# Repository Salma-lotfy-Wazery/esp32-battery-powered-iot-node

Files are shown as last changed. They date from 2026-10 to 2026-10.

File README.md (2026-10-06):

# 📡 ESP32 Battery-Powered IoT Telemetry Node



[]()
[]()

A compact, reliable, and energy-efficient custom hardware platform engineered for wireless sensor monitoring and remote telemetry applications. Built around the **Espressif ESP32-WROOM-32** module, this node combines precision sensor interfaces, on-board Lithium-Polymer (LiPo) battery charge management, and a modern USB-C interface into a robust 2-layer PCB layout.

---

## 🖼️ 3D Render & Visual Inspection

<p align="center">
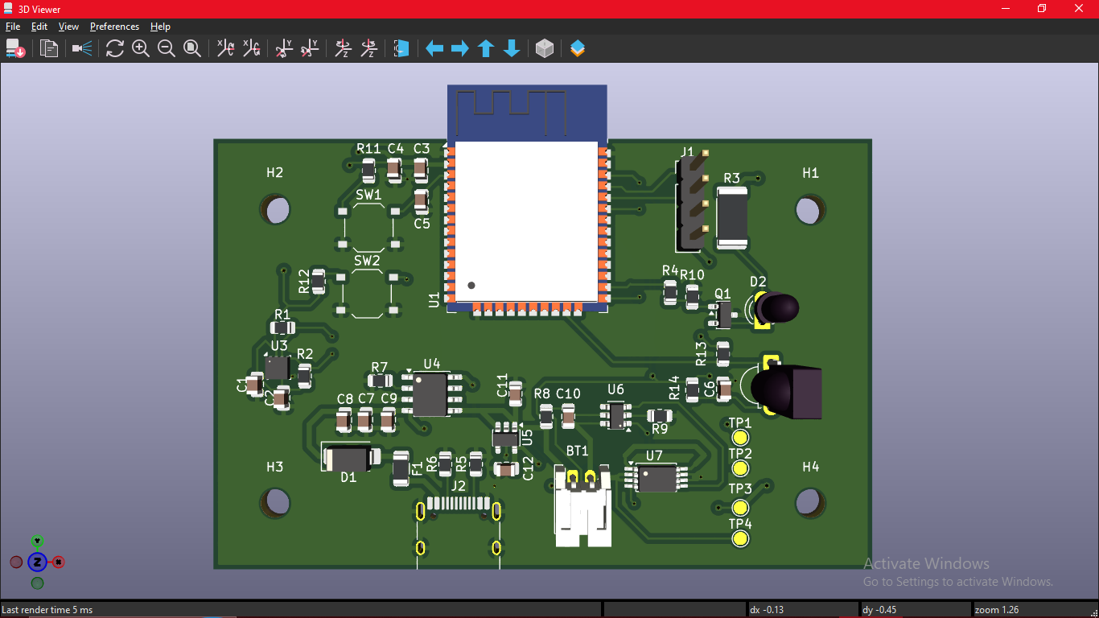
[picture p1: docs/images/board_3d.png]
ESP32 IoT Node 3D Board Perspective
  
</p>

<p align="center">
  <em>Figure 1: Full 3D assembly render of the ESP32 Battery-Powered IoT Node.</em>
</p>

---

## ⚡ Technical Architecture & Hardware Features

### 1. Power Distribution & Battery Management
- **USB Interface**: USB Type-C receptacle wired for standard 5V VBUS power negotiation and system integration.
- **Battery Charging**: Integrated Single-Cell Li-Ion/LiPo battery management circuit (Linear Constant-Current / Constant-Voltage charging) with charge-status telemetry.
- **Voltage Regulation**: Low-Dropout (LDO) regulator delivering a stable, low-noise 3.3V power rail to ensure radio stability during Wi-Fi/BLE bursts.
- **Power Path & Protection**: Reverse protection and decoupling networks mitigating voltage ripple across analog and digital loads.

### 2. Microcontroller & Sensor Interfaces
- **MCU**: ESP32-WROOM-32 high-performance dual-core 32-bit Tensilica Xtensa LX6 microprocessor operating at up to 240 MHz.
- **Wireless Connectivity**: Integrated 2.4 GHz 802.11 b/g/n Wi-Fi and Bluetooth v4.2 / BLE.
- **Telemetry Bus**: Dedicated I2C bus featuring proper pull-up resistors for multi-sensor interfacing (environmental, motion, and ambient instrumentation).
- **Control & Diagnostics**: Hardware Pushbuttons for system `EN` (Reset) and `IO0` (Bootloader Strap), plus dedicated LED indicators for power and user status.
- **Test Points**: Strategic analog and digital hardware test points for oscilloscope probing and rapid bring-up validation.

---

## 📐 PCB Layout & Documentation

| Isometric 3D Model | Top View / Layout View |
| :---: | :---: |
| 3D Angle | Top View |

### PCB Specifications
- **Board Stackup**: 2-Layer FR4 Standard
- **Finished Copper Weight**: 1 oz (35 µm)
- **Ground Strategy**: Continuous, low-impedance ground return planes on both Top and Bottom layers stitched with vias.
- **Mechanical Form Factor**: Designed with 4 corner mounting holes for standard standoffs and protective enclosure mounting.

---
## ⚖️ License

This project is licensed under the CERN Open Hardware Licence Version 2 - Weakly Reciprocal (CERN-OHL-W-2.0). See the [LICENSE](LICENSE) file for more information.

## 📂 Repository File Tree

├── project 1 pcb.kicad_pcb              # Multi-layer PCB routing and layout
├── .gitignore                           # Excludes KiCad temporary, backup & lock files
└── README.md                            # Primary project documentation

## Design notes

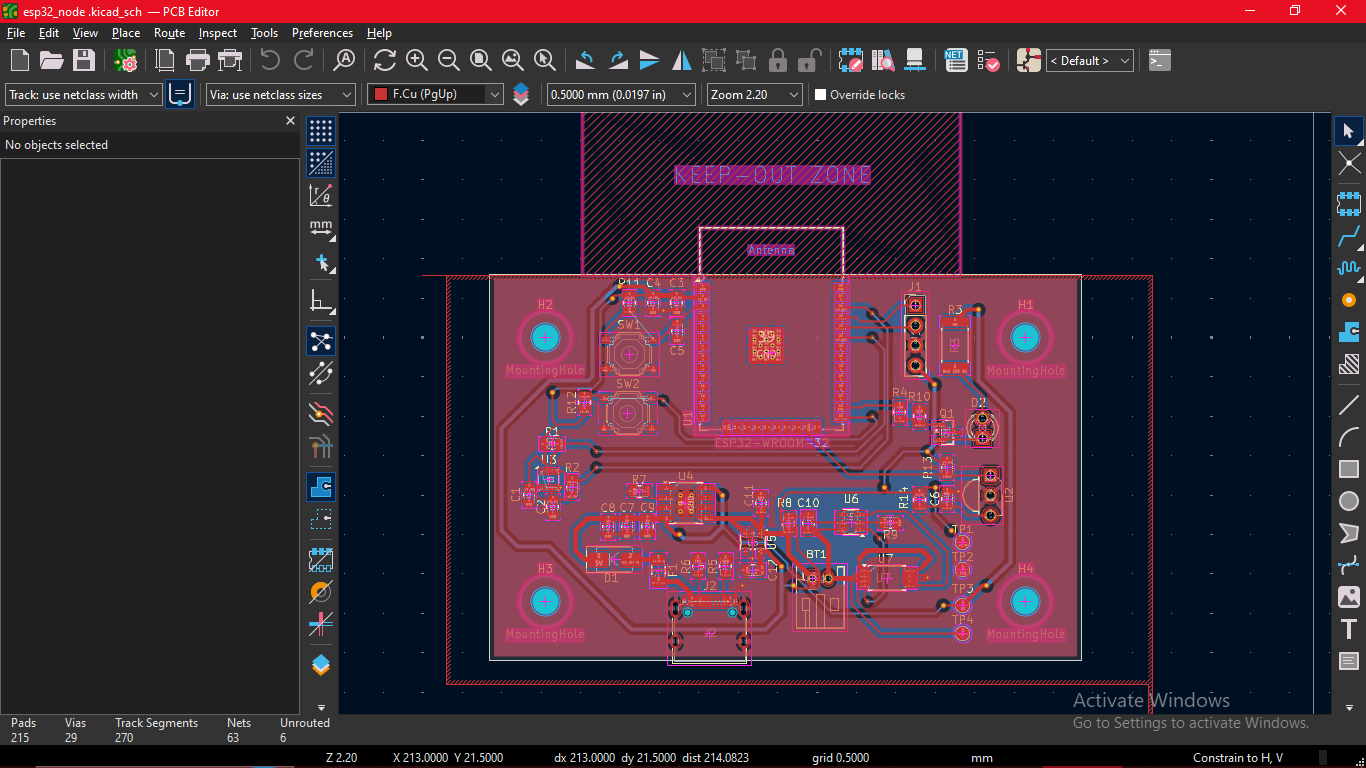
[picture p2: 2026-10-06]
docs/images/board _2d .png

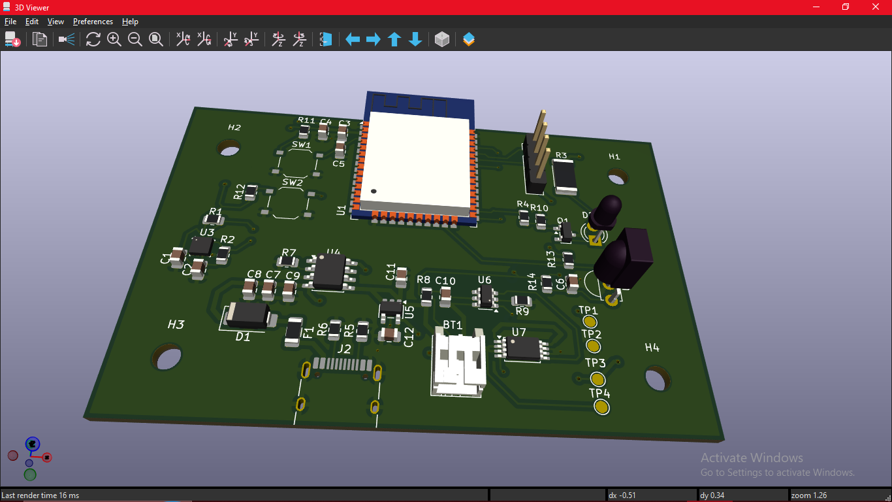
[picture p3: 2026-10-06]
docs/images/board_3d .png

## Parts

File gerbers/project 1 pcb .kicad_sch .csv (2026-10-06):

Reference | Qty | Value | DNP | Exclude from BOM | Exclude from Board | Exclude from Simulation | Exclude from Position Files | Footprint | Datasheet
BT1 | 1 | Battery_Cell |  |  |  |  | ${EXCLUDE_FROM_POS_FILES} | Connector_JST:JST_PH_S2B-PH-K_1x02_P2.00mm_Horizontal
C1,C2,C3,C5,C6,C9,C10 | 7 | 100n |  |  |  |  | ${EXCLUDE_FROM_POS_FILES} | Capacitor_SMD:C_0805_2012Metric
C4,C7,C8,C11,C12 | 5 | 10u |  |  |  |  | ${EXCLUDE_FROM_POS_FILES} | Capacitor_SMD:C_0805_2012Metric
D1 | 1 | SS14 |  |  |  |  | ${EXCLUDE_FROM_POS_FILES} | Diode_SMD:D_SMA | https://www.vishay.com/docs/88746/ss12.pdf
D2 | 1 | TSAL4400 |  |  |  |  | ${EXCLUDE_FROM_POS_FILES} | LED_THT:LED_D3.0mm_IRBlack | http://www.vishay.com/docs/81006/tsal4400.pdf
F1 | 1 | 2A |  |  |  |  | ${EXCLUDE_FROM_POS_FILES} | Fuse:Fuse_1206_3216Metric
J1 | 1 | Conn_01x04_Pin |  |  |  |  | ${EXCLUDE_FROM_POS_FILES} | Connector_PinHeader_2.54mm:PinHeader_1x04_P2.54mm_Vertical
J2 | 1 | USB_C_Receptacle_USB2.0_16P |  |  |  |  | ${EXCLUDE_FROM_POS_FILES} | Connector_USB:USB_C_Receptacle_HRO_TYPE-C-31-M-12 | https://www.usb.org/sites/default/files/documents/usb_type-c.zip
Q1 | 1 | AO3400A |  |  |  |  | ${EXCLUDE_FROM_POS_FILES} | Package_TO_SOT_SMD:SOT-23 | http://www.aosmd.com/pdfs/datasheet/AO3400A.pdf
R1,R2,R12 | 3 | 4.7k |  |  |  |  | ${EXCLUDE_FROM_POS_FILES} | Resistor_SMD:R_0805_2012Metric
R3 | 1 | 22 |  |  |  |  | ${EXCLUDE_FROM_POS_FILES} | Resistor_SMD:R_2512_6332Metric
R4,R8,R14 | 3 | 100 |  |  |  |  | ${EXCLUDE_FROM_POS_FILES} | Resistor_SMD:R_0805_2012Metric
R5,R6 | 2 | 5.1k |  |  |  |  | ${EXCLUDE_FROM_POS_FILES} | Resistor_SMD:R_0805_2012Metric
R7 | 1 | 1.2k |  |  |  |  | ${EXCLUDE_FROM_POS_FILES} | Resistor_SMD:R_0805_2012Metric
R9 | 1 | 1k |  |  |  |  | ${EXCLUDE_FROM_POS_FILES} | Resistor_SMD:R_0805_2012Metric
R10,R11,R13 | 3 | 10k |  |  |  |  | ${EXCLUDE_FROM_POS_FILES} | Resistor_SMD:R_0805_2012Metric
SW1,SW2 | 2 | SW_Push |  |  |  |  | ${EXCLUDE_FROM_POS_FILES} | Button_Switch_SMD:SW_Push_1P1T_XKB_TS-1187A
TP1,TP2,TP3,TP4 | 4 | TestPoint |  |  |  |  | ${EXCLUDE_FROM_POS_FILES} | TestPoint:TestPoint_Pad_D1.5mm
U1 | 1 | ESP32-WROOM-32 |  |  |  |  | ${EXCLUDE_FROM_POS_FILES} | RF_Module:ESP32-WROOM-32 | https://www.espressif.com/sites/default/files/documentation/esp32-wroom-32_datasheet_en.pdf
U2 | 1 | TSOP382xx |  |  |  |  | ${EXCLUDE_FROM_POS_FILES} | OptoDevice:Vishay_MINICAST-3Pin | http://www.vishay.com/docs/82491/tsop382.pdf
U3 | 1 | BME280 |  |  |  |  | ${EXCLUDE_FROM_POS_FILES} | Package_LGA:Bosch_LGA-8_2.5x2.5mm_P0.65mm_ClockwisePinNumbering | https://www.bosch-sensortec.com/media/boschsensortec/downloads/datasheets/bst-bme280-ds002.pdf
U4 | 1 | TP4056-42-ESOP8 |  |  |  |  | ${EXCLUDE_FROM_POS_FILES} | Package_SO:SOIC-8-1EP_3.9x4.9mm_P1.27mm_EP2.29x3mm_ThermalVias | https://www.lcsc.com/datasheet/lcsc_datasheet_2410121619_TOPPOWER-Nanjing-Extension-Microelectronics-TP4056-42-ESOP8_C16581.pdf
U5 | 1 | AP2112K-3.3 |  |  |  |  | ${EXCLUDE_FROM_POS_FILES} | Package_TO_SOT_SMD:SOT-23-5 | https://www.diodes.com/assets/Datasheets/AP2112.pdf
U6 | 1 | DW01A |  |  |  |  | ${EXCLUDE_FROM_POS_FILES} | Package_TO_SOT_SMD:SOT-23-6 | https://hmsemi.com/downfile/DW01A.PDF
U7 | 1 | FS8205A |  |  |  |  | ${EXCLUDE_FROM_POS_FILES} | Package_SO:TSSOP-8_4.4x3mm_P0.65mm

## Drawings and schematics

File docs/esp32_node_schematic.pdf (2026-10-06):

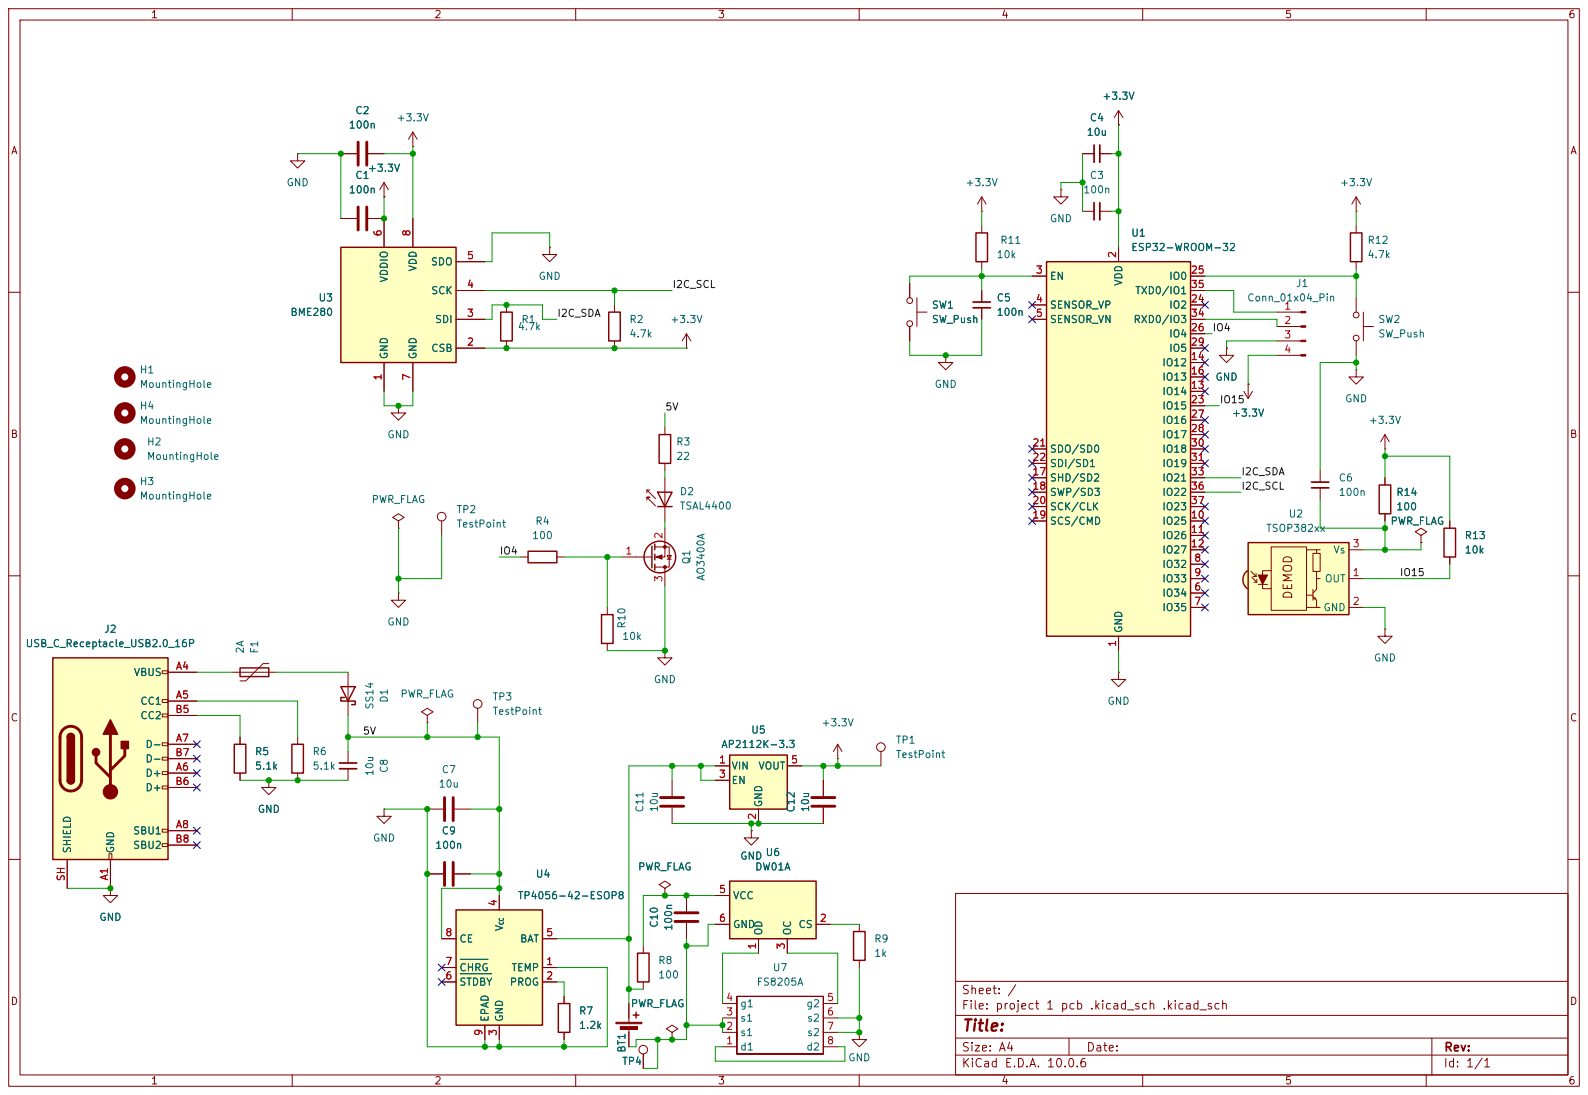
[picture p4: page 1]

Size: A4 | Rev:
KiCad E.D.A. 10.0.6 | Id: 1/1

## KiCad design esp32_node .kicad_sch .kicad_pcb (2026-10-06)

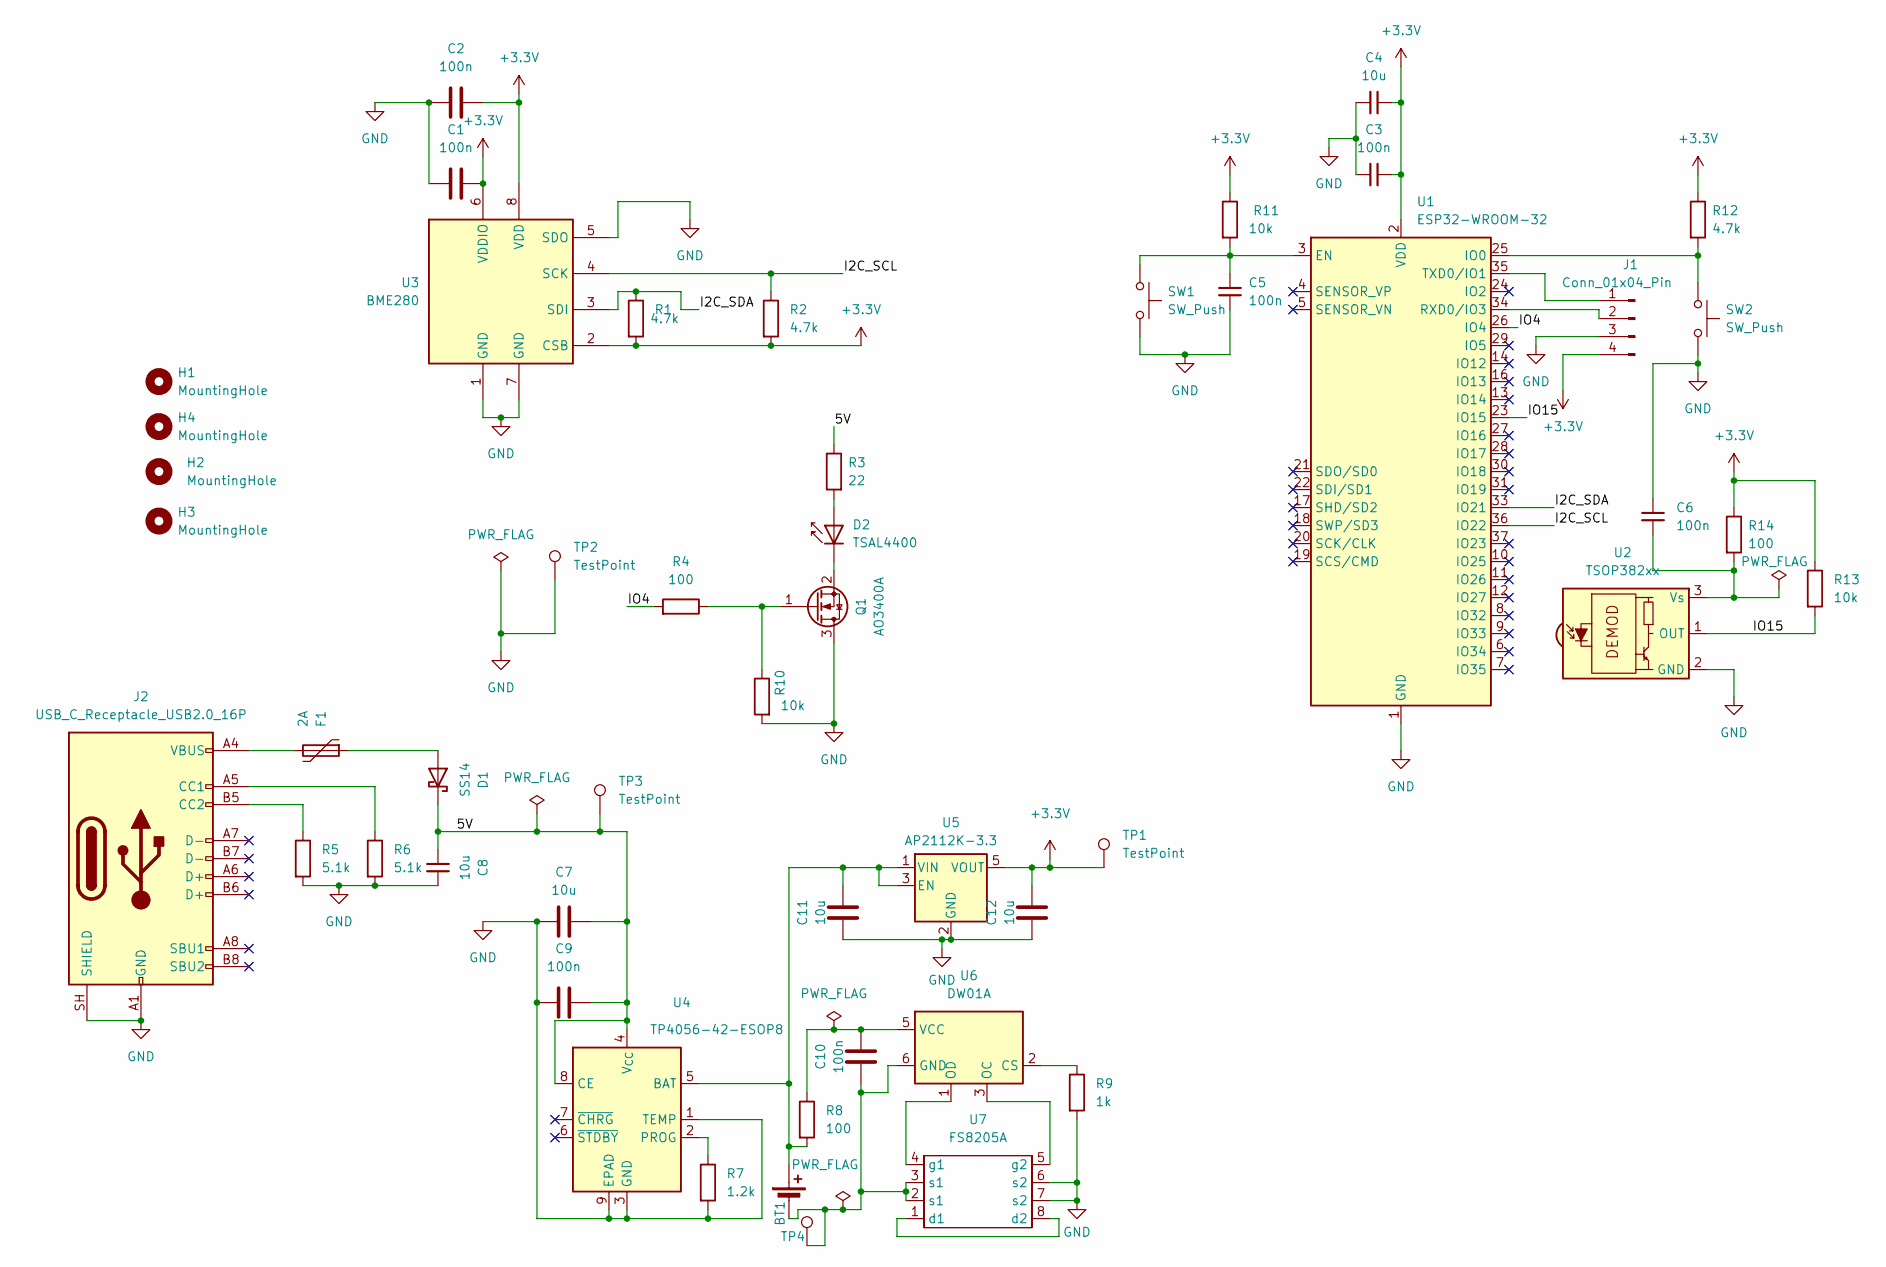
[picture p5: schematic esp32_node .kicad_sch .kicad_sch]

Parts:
BT1: Battery_Cell; JST_PH_S2B-PH-K_1x02_P2.00mm_Horizontal
C1, C2, C3, C5, C6, C9, C10: 100n; C_0805_2012Metric
C4, C7, C8, C11, C12: 10u; C_0805_2012Metric
D1: SS14; D_SMA
D2: TSAL4400; LED_D3.0mm_IRBlack
F1: 2A; Fuse_1206_3216Metric
H1, H2, H3, H4: MountingHole; MountingHole_3.2mm_M3
J1: Conn_01x04_Pin; PinHeader_1x04_P2.54mm_Vertical
J2: USB_C_Receptacle_USB2.0_16P; USB_C_Receptacle_HRO_TYPE-C-31-M-12
Q1: AO3400A; SOT-23
R1, R2, R12: 4.7k; R_0805_2012Metric
R3: 22; R_2512_6332Metric
R4, R8, R14: 100; R_0805_2012Metric
R5, R6: 5.1k; R_0805_2012Metric
R7: 1.2k; R_0805_2012Metric
R9: 1k; R_0805_2012Metric
R10, R11, R13: 10k; R_0805_2012Metric
SW1, SW2: SW_Push; SW_Push_1P1T_XKB_TS-1187A
TP1, TP2, TP3, TP4: TestPoint; TestPoint_Pad_D1.5mm
U1: ESP32-WROOM-32; LCSC part C82899
U2: TSOP382xx; Vishay_MINICAST-3Pin
U3: BME280; Bosch_LGA-8_2.5x2.5mm_P0.65mm_ClockwisePinNumbering
U4: TP4056-42-ESOP8; SOIC-8-1EP_3.9x4.9mm_P1.27mm_EP2.29x3mm_ThermalVias
U5: AP2112K-3.3; SOT-23-5
U6: DW01A; SOT-23-6
U7: FS8205A; TSSOP-8_4.4x3mm_P0.65mm

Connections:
+3.3V: C1.2, C2.2, C3.1, C4.1, C12.1, J1.4, R1.2, R2.2, R11.1, R12.1, R13.1, R14.1, TP1.1 (1_1), U1.2 (VDD), U3.2 (CSB), U3.6 (VDDIO), U3.8 (VDD), U5.5 (VOUT)
/5V: C7.2, C8.1, C9.2, D1.1 (K), R3.1, TP3.1 (1_1), U4.4 (V_{CC}), U4.8 (CE)
/I2C_SCL: R2.1, U1.36 (IO22), U3.4 (SCK)
/I2C_SDA: R1.1, U1.33 (IO21), U3.3 (SDI)
/IO4: R4.2, U1.26 (IO4)
/IO15: R13.2, U1.23 (IO15), U2.1 (OUT)
GND: C1.1, C2.1, C3.2, C4.2, C5.1, C6.1, C7.1, C8.2, C9.1, C11.2, C12.2, J1.3, J2.A1 (GND), J2.A12 (GND), J2.B1 (GND), J2.B12 (GND), J2.SH (SHIELD), Q1.3 (D), R5.2, R6.2, R7.2, R9.2, R10.2, SW1.2, SW2.2, TP2.1 (1_1), U1.1 (GND), U1.15 (GND), U1.38 (GND), U1.39 (GND), U2.2 (GND), U3.1 (GND), U3.5 (SDO), U3.7 (GND), U4.1 (TEMP), U4.3 (GND), U4.9 (EPAD), U5.2 (GND), U7.6 (s2), U7.7 (s2)
unnamed: BT1.1 (+), C11.1, R8.2, U4.5 (BAT), U5.1 (VIN), U5.3 (EN)
unnamed: BT1.2 (-), C10.2, TP4.1 (1_1), U6.6 (GND), U7.2 (s1), U7.3 (s1)
unnamed: D1.2 (A), F1.1
unnamed: D2.2 (A), R3.2
unnamed: D2.1 (K), Q1.2 (S)
unnamed: F1.2, J2.A4 (VBUS), J2.A9 (VBUS), J2.B4 (VBUS), J2.B9 (VBUS)
unnamed: J1.1, U1.35 (TXD0/IO1)
unnamed: J1.2, U1.34 (RXD0/IO3)
unnamed: J2.A5 (CC1), R6.1
unnamed: J2.B5 (CC2), R5.1
unnamed: Q1.1 (G), R4.1, R10.1
unnamed: C5.2, R11.2, SW1.1, U1.3 (EN)
unnamed: R12.2, SW2.1, U1.25 (IO0)
unnamed: C6.2, R14.2, U2.3 (Vs)
unnamed: R7.1, U4.2 (PROG)
unnamed: R9.1, U6.2 (CS)
unnamed: U6.3 (OC), U7.5 (g2)
unnamed: U6.1 (OD), U7.4 (g1)
unnamed: C10.1, R8.1, U6.5 (VCC)
unnamed: U7.1 (d1), U7.8 (d2)

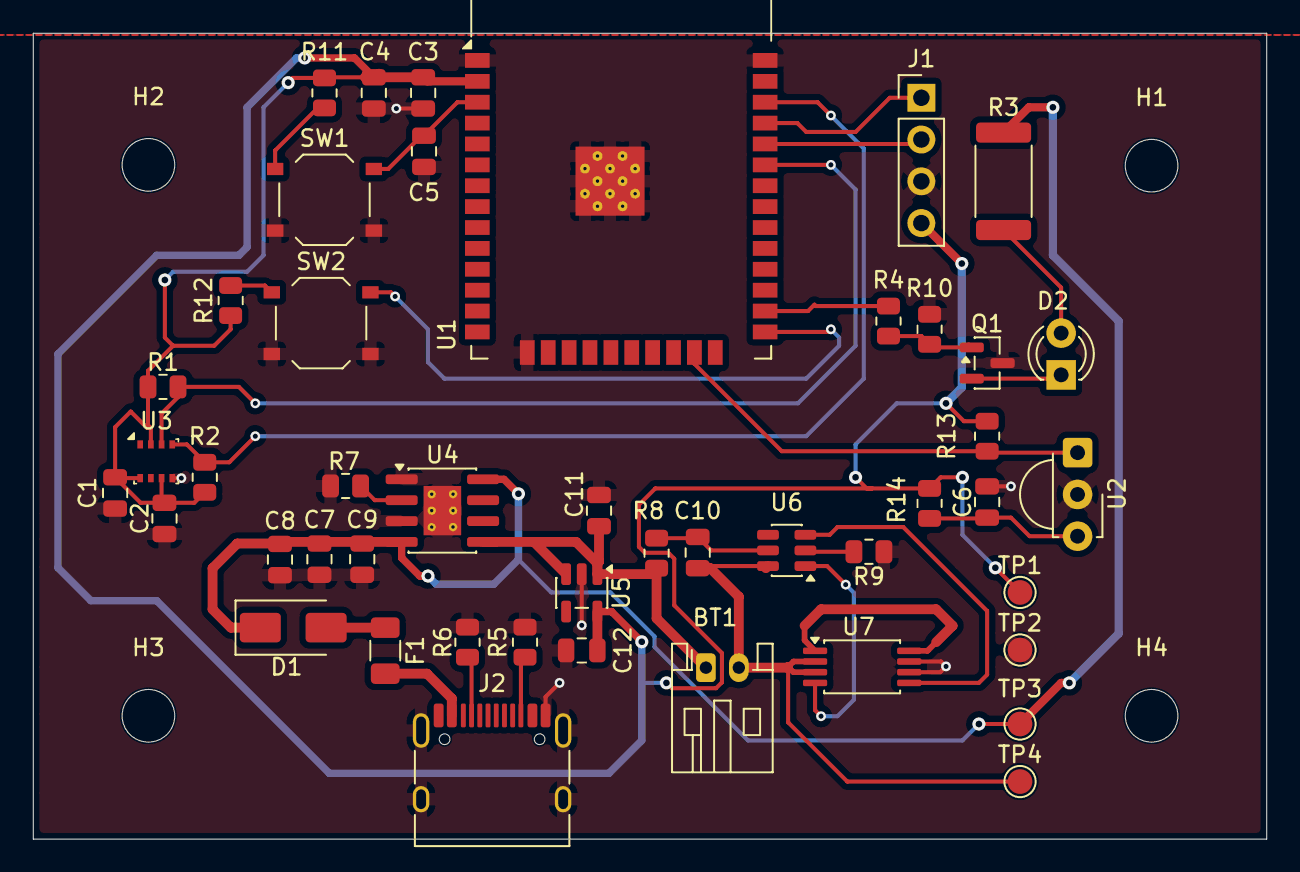
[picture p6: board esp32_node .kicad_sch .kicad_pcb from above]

Board: 2 copper layers, 75.0 x 49.0 mm, 50 parts (0 on the bottom side), 27 nets.

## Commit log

2026-10-06 Initial commit: KiCad schematic and PCB layout files
    [project 1 pcb .kicad_sch .kicad_pcb, project 1 pcb .kicad_sch .kicad_sch]
2026-10-06 Untrack kicad_prl local settings file
2026-10-06 Add documentation: schematic PDF and board renders
2026-10-06 Add README for ESP32 IoT Telemetry Node
    Added comprehensive documentation for the ESP32 Battery-Powered IoT Telemetry Node, including technical architecture, hardware features, PCB layout, and repository file structure.
2026-10-06 Add production manufacturing Gerber and Drill files
    [esp32_node .kicad_sch -B_Cu.gbl, esp32_node .kicad_sch -B_Mask.gbs, esp32_node .kicad_sch -B_Paste.gbp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]
2026-10-06 Update project files, gerbers, and release
    [esp32_node .kicad_sch .kicad_pcb, esp32_node .kicad_sch .kicad_sch]
2026-10-06 Ignore and remove KiCad lock files (.lck)
2026-10-06 Add BOM and CPL placement files for assembly
    [project 1 pcb .kicad_sch .csv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]

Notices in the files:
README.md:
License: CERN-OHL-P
